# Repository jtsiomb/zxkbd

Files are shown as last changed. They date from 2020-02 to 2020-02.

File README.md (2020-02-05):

ZX Spectrum PS/2 keyboard controller
====================================

About
-----
This project is an PS/2 keyboard controller for the ZX Spectrum. It makes it
possible to connect and use an external PS/2 keyboard with the spectrum. It's
based on the a500kbd code: https://github.com/jtsiomb/a500kbd

The PS/2 keyboard controller is built around an AVR atmega168 microcontroller.
The firmware reads PS/2 keyboard scancodes, maintains a virtual spectrum
keyboard state, and monitors the address bus to keep the data lines going into
the ULA continuously up to date with the selected key row state.

NOTE: not done. check back soon.

License
-------
Copyright (C) 2020 John Tsiombikas <nuclear@member.fsf.org>

You are free to use, reproduce, modify, redistribute any parts of this project,
provided you make any derivative work you release, freely available under the
same terms.

More specifically the hardware design is released under the Creative Commons
Attribution Share-Alike license (see `LICENSE.hw` for details), and the
software/firmware is released under the GNU General Public License v3, or later
(see `LICENSE.fw` for details).

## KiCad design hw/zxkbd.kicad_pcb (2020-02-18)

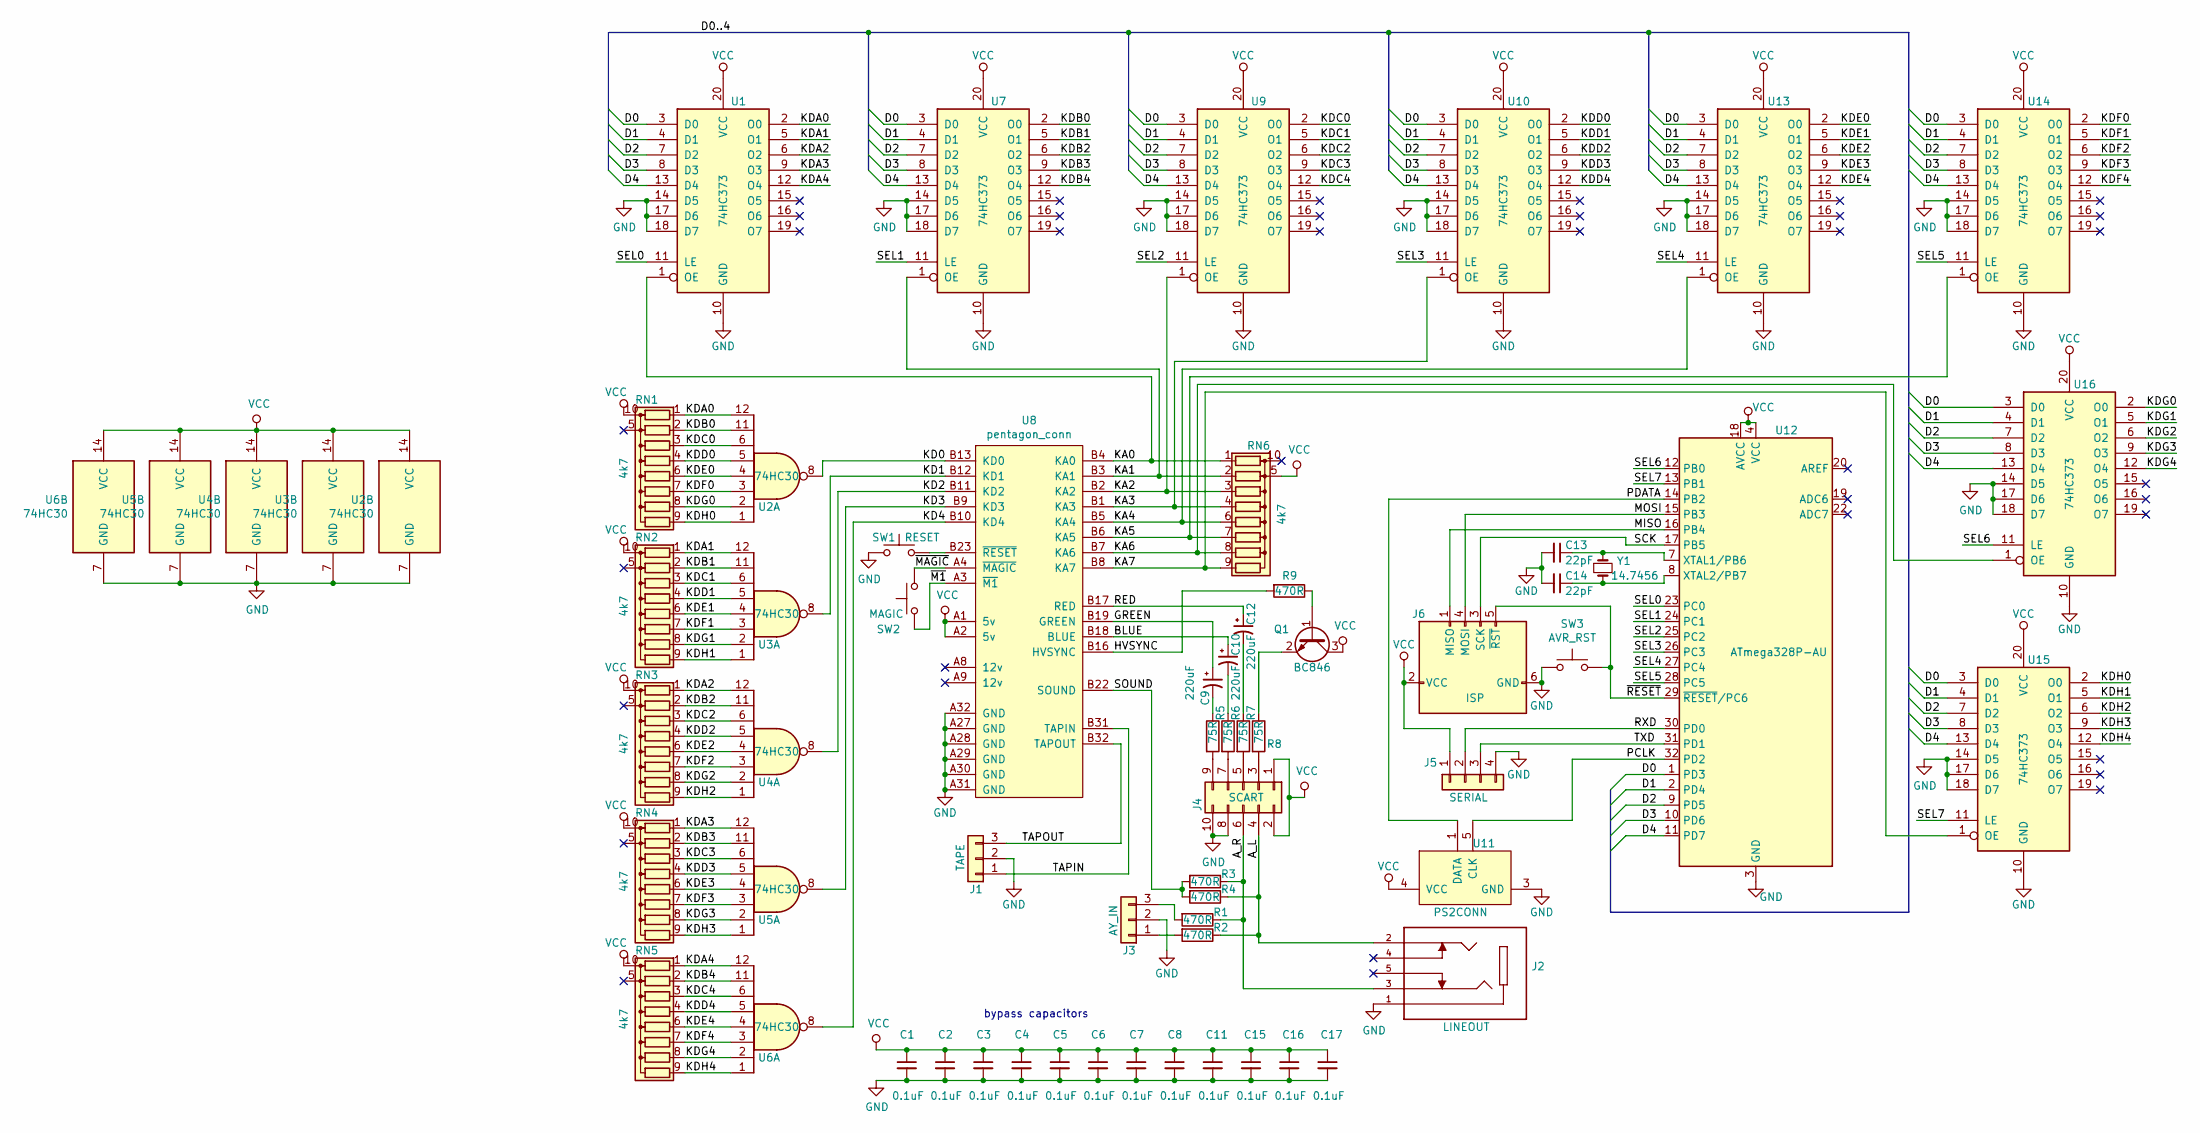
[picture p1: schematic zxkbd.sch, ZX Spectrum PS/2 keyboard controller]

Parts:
C1, C2, C3, C4, C5, C6, C7, C8, C11, C15, C16, C17: 0.1uF; C_0805_2012Metric_Pad1.15x1.40mm_HandSolder
C9, C10, C12: 220uF; CP_Elec_6.3x7.7
C13, C14: 22pF; C_0805_2012Metric_Pad1.15x1.40mm_HandSolder
J1: TAPE; PinHeader_1x03_P2.54mm_Vertical
J2: LINEOUT; cui_sj1-3525ng
J3: AY_IN; PinHeader_1x03_P2.54mm_Vertical
J4: SCART; IDC-Header_2x05_P2.54mm_Vertical
J5: SERIAL; PinHeader_1x04_P2.54mm_Vertical
J6: ISP; IDC-Header_2x03_P2.54mm_Vertical
Q1: BC846; SOT-23
R1, R2, R3, R4, R9: 470R; R_0805_2012Metric_Pad1.15x1.40mm_HandSolder
R5, R6, R7, R8: 75R; R_0805_2012Metric_Pad1.15x1.40mm_HandSolder
RN1, RN2, RN3, RN4, RN5, RN6: 4k7; R_Array_Convex_5x1206
SW1: RESET; SW_Push_1P1T_NO_6x6mm_H9.5mm
SW2: MAGIC; SW_Push_1P1T_NO_6x6mm_H9.5mm
SW3: AVR_RST; SW_Push_1P1T_NO_6x6mm_H9.5mm
U1, U7, U9, U10, U13, U14, U15, U16: 74HC373; SOIC-20W_7.5x12.8mm_P1.27mm
U2, U3, U4, U5, U6: 74HC30; SOIC-14_3.9x8.7mm_P1.27mm
U8: pentagon_conn; pentconn
U11: PS2CONN; ps2conn
U12: ATmega328P-AU; TQFP-32_7x7mm_P0.8mm
Y1: 14.7456; Crystal_SMD_ECS_CSM3X-2Pin_7.6x4.1mm

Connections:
/A_L: J2.2, J4.4, R2.1, R4.1
/A_R: J2.3, J4.6, R1.1, R3.1
/BLUE: C10.1, U8.B18 (BLUE)
/D0: U1.3 (D0), U7.3 (D0), U9.3 (D0), U10.3 (D0), U12.1 (PD3), U13.3 (D0), U14.3 (D0), U15.3 (D0), U16.3 (D0)
/D1: U1.4 (D1), U7.4 (D1), U9.4 (D1), U10.4 (D1), U12.2 (PD4), U13.4 (D1), U14.4 (D1), U15.4 (D1), U16.4 (D1)
/D2: U1.7 (D2), U7.7 (D2), U9.7 (D2), U10.7 (D2), U12.9 (PD5), U13.7 (D2), U14.7 (D2), U15.7 (D2), U16.7 (D2)
/D3: U1.8 (D3), U7.8 (D3), U9.8 (D3), U10.8 (D3), U12.10 (PD6), U13.8 (D3), U14.8 (D3), U15.8 (D3), U16.8 (D3)
/D4: U1.13 (D4), U7.13 (D4), U9.13 (D4), U10.13 (D4), U12.11 (PD7), U13.13 (D4), U14.13 (D4), U15.13 (D4), U16.13 (D4)
/GREEN: C9.1, U8.B19 (GREEN)
/HVSYNC: R9.2, U8.B16 (HVSYNC)
/KA0: RN6.1 (R1), U1.1 (OE), U8.B4 (KA0)
/KA1: RN6.2 (R2), U7.1 (OE), U8.B3 (KA1)
/KA2: RN6.3 (R3), U8.B2 (KA2), U9.1 (OE)
/KA3: RN6.4 (R4), U8.B1 (KA3), U10.1 (OE)
/KA4: RN6.6 (R6), U8.B5 (KA4), U13.1 (OE)
/KA5: RN6.7 (R7), U8.B6 (KA5), U14.1 (OE)
/KA6: RN6.8 (R8), U8.B7 (KA6), U16.1 (OE)
/KA7: RN6.9 (R9), U8.B8 (KA7), U15.1 (OE)
/KD0: U2.8, U8.B13 (KD0)
/KD1: U3.8, U8.B12 (KD1)
/KD2: U4.8, U8.B11 (KD2)
/KD3: U5.8, U8.B9 (KD3)
/KD4: U6.8, U8.B10 (KD4)
/KDA0: RN1.1 (R1), U1.2 (O0), U2.12
/KDA1: RN2.1 (R1), U1.5 (O1), U3.12
/KDA2: RN3.1 (R1), U1.6 (O2), U4.12
/KDA3: RN4.1 (R1), U1.9 (O3), U5.12
/KDA4: RN5.1 (R1), U1.12 (O4), U6.12
/KDB0: RN1.2 (R2), U2.11, U7.2 (O0)
/KDB1: RN2.2 (R2), U3.11, U7.5 (O1)
/KDB2: RN3.2 (R2), U4.11, U7.6 (O2)
/KDB3: RN4.2 (R2), U5.11, U7.9 (O3)
/KDB4: RN5.2 (R2), U6.11, U7.12 (O4)
/KDC0: RN1.3 (R3), U2.6, U9.2 (O0)
/KDC1: RN2.3 (R3), U3.6, U9.5 (O1)
/KDC2: RN3.3 (R3), U4.6, U9.6 (O2)
/KDC3: RN4.3 (R3), U5.6, U9.9 (O3)
/KDC4: RN5.3 (R3), U6.6, U9.12 (O4)
/KDD0: RN1.4 (R4), U2.5, U10.2 (O0)
/KDD1: RN2.4 (R4), U3.5, U10.5 (O1)
/KDD2: RN3.4 (R4), U4.5, U10.6 (O2)
/KDD3: RN4.4 (R4), U5.5, U10.9 (O3)
/KDD4: RN5.4 (R4), U6.5, U10.12 (O4)
/KDE0: RN1.6 (R6), U2.4, U13.2 (O0)
/KDE1: RN2.6 (R6), U3.4, U13.5 (O1)
/KDE2: RN3.6 (R6), U4.4, U13.6 (O2)
/KDE3: RN4.6 (R6), U5.4, U13.9 (O3)
/KDE4: RN5.6 (R6), U6.4, U13.12 (O4)
/KDF0: RN1.7 (R7), U2.3, U14.2 (O0)
/KDF1: RN2.7 (R7), U3.3, U14.5 (O1)
/KDF2: RN3.7 (R7), U4.3, U14.6 (O2)
/KDF3: RN4.7 (R7), U5.3, U14.9 (O3)
/KDF4: RN5.7 (R7), U6.3, U14.12 (O4)
/KDG0: RN1.8 (R8), U2.2, U16.2 (O0)
/KDG1: RN2.8 (R8), U3.2, U16.5 (O1)
/KDG2: RN3.8 (R8), U4.2, U16.6 (O2)
/KDG3: RN4.8 (R8), U5.2, U16.9 (O3)
/KDG4: RN5.8 (R8), U6.2, U16.12 (O4)
/KDH0: RN1.9 (R9), U2.1, U15.2 (O0)
/KDH1: RN2.9 (R9), U3.1, U15.5 (O1)
/KDH2: RN3.9 (R9), U4.1, U15.6 (O2)
/KDH3: RN4.9 (R9), U5.1, U15.9 (O3)
/KDH4: RN5.9 (R9), U6.1, U15.12 (O4)
/MISO: J6.1 (MISO), U12.16 (PB4)
/MOSI: J6.4 (MOSI), U12.15 (PB3)
/PCLK: U11.5 (CLK), U12.32 (PD2)
/PDATA: U11.1 (DATA), U12.14 (PB2)
/RED: C12.1, U8.B17 (RED)
/RXD: J5.2, U12.30 (PD0)
/SCK: J6.3 (SCK), U12.17 (PB5)
/SEL0: U1.11 (LE), U12.23 (PC0)
/SEL1: U7.11 (LE), U12.24 (PC1)
/SEL2: U9.11 (LE), U12.25 (PC2)
/SEL3: U10.11 (LE), U12.26 (PC3)
/SEL4: U12.27 (PC4), U13.11 (LE)
/SEL5: U12.28 (PC5), U14.11 (LE)
/SEL6: U12.12 (PB0), U16.11 (LE)
/SEL7: U12.13 (PB1), U15.11 (LE)
/SOUND: R3.2, R4.2, U8.B22 (SOUND)
/TAPIN: J1.1, U8.B31 (TAPIN)
/TAPOUT: J1.3, U8.B32 (TAPOUT)
/TXD: J5.3, U12.31 (PD1)
/~M1: SW2.1, U8.A3 (~M1)
/~MAGIC: SW2.2, U8.A4 (~MAGIC)
/~RESET: J6.5 (~RST), SW3.2, U12.29 (~RESET~/PC6)
GND: C1.2, C2.2, C3.2, C4.2, C5.2, C6.2, C7.2, C8.2, C11.2, C13.2, C14.2, C15.2, C16.2, C17.2, J1.2, J2.1, J3.2, J4.8, J4.10, J5.4, J6.6 (GND), SW1.1, SW3.1, U1.10 (GND), U1.14 (D5), U1.17 (D6), U1.18 (D7), U2.7 (GND), U3.7 (GND), U4.7 (GND), U5.7 (GND), U6.7 (GND), U7.10 (GND), U7.14 (D5), U7.17 (D6), U7.18 (D7), U8.A27 (GND), U8.A28 (GND), U8.A29 (GND), U8.A30 (GND), U8.A31 (GND), U8.A32 (GND), U9.10 (GND), U9.14 (D5), U9.17 (D6), U9.18 (D7), U10.10 (GND), U10.14 (D5), U10.17 (D6), U10.18 (D7), U11.3 (GND), U12.3 (GND), U12.5 (GND), U12.21 (GND), U13.10 (GND), U13.14 (D5), U13.17 (D6), U13.18 (D7), U14.10 (GND), U14.14 (D5), U14.17 (D6), U14.18 (D7), U15.10 (GND), U15.14 (D5), U15.17 (D6), U15.18 (D7), U16.10 (GND), U16.14 (D5), U16.17 (D6), U16.18 (D7)
unnamed: C9.2, R5.1
unnamed: C10.2, R6.1
unnamed: C12.2, R7.1
unnamed: C13.1, U12.7 (XTAL1/PB6), Y1.1
unnamed: C14.1, U12.8 (XTAL2/PB7), Y1.2
unnamed: J3.1, R2.2
unnamed: J3.3, R1.2
unnamed: J4.3, R8.2
unnamed: J4.5, R7.2
unnamed: J4.7, R6.2
unnamed: J4.9, R5.2
unnamed: Q1.1 (B), R9.1
unnamed: Q1.2 (E), R8.1
unnamed: SW1.2, U8.B23 (~RESET)
VCC: C1.1, C2.1, C3.1, C4.1, C5.1, C6.1, C7.1, C8.1, C11.1, C15.1, C16.1, C17.1, J4.1, J4.2, J5.1, J6.2 (VCC), Q1.3 (C), RN1.10 (common), RN2.10 (common), RN3.10 (common), RN4.10 (common), RN5.10 (common), RN6.5 (common), U1.20 (VCC), U2.14 (VCC), U3.14 (VCC), U4.14 (VCC), U5.14 (VCC), U6.14 (VCC), U7.20 (VCC), U8.A1 (5v), U8.A2 (5v), U9.20 (VCC), U10.20 (VCC), U11.4 (VCC), U12.4 (VCC), U12.6 (VCC), U12.18 (AVCC), U13.20 (VCC), U14.20 (VCC), U15.20 (VCC), U16.20 (VCC)

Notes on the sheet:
bypass capacitors

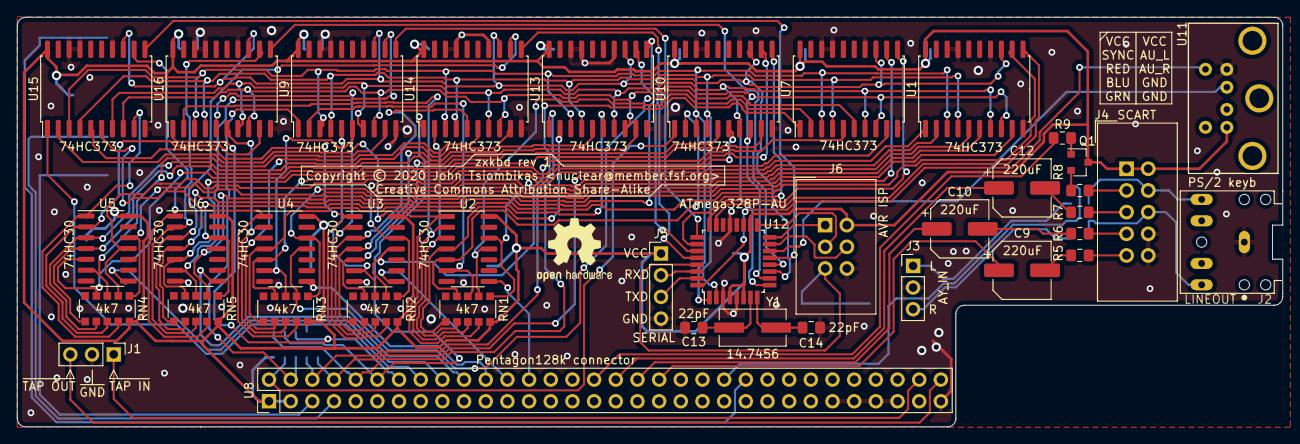
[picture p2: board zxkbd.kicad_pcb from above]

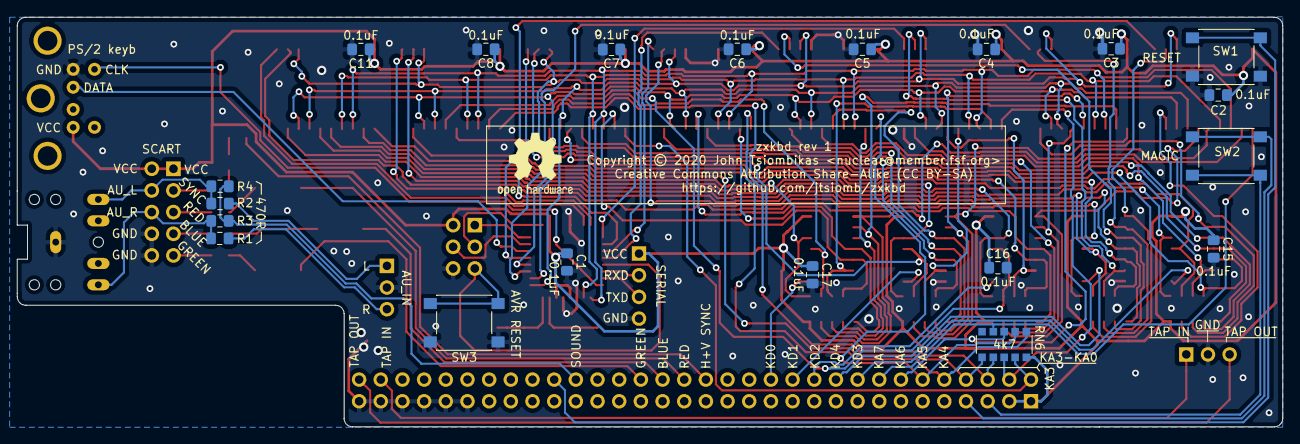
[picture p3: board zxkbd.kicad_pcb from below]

Board: 2 copper layers, 148.3 x 48.0 mm, 59 parts (20 on the bottom side), 101 nets.

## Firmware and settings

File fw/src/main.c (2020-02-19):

#include <stdio.h>
#include <ctype.h>
#include <avr/io.h>
#include <avr/interrupt.h>
#include <util/delay.h>
#include "serial.h"
#include "scantbl.h"
#include "ps2kbd.h"
#include "defs.h"
#include "timer.h"
#include "zxkbd.h"
#include "ansi.h"

enum {
	KF_BRK = 1,
	KF_EXT = 2,
	KF_EXT1 = 4,
};
#define KF_TRANSIENT	0x0f
#define KF_STICKY		0xf0

#define RESET_WAIT 1000



int main(void)
{
	unsigned int keyflags = 0;
	unsigned char c;
	int keycode;

	/* disable all pullups globally */
	MCUCR |= 1 << PUD;

	/* start with all latch signals off (high) */
	DDRC = 0xff;
	PORTC = 0xff;
	DDRB = 3;
	PORTB = 3;

	/* data bits as outputs */
	DDRD = 0xf8;
	PORTD = 0xf8;

	EIMSK = 0;	/* mask external interrupts */
	EICRA = 1 << ISC01;	/* falling edge of PCLK triggers interrupt */

	init_timer();

	/* initialize the UART and enable interrupts */
	init_serial(9600);
	sei();

	ansi_reset();
	ansi_clearscr();
	ansi_cursor(0);
	printf("PS/2 keyboard controller - John Tsiombikas <nuclear@member.fsf.org>\r\n");
	fflush(stdout);

	EIMSK = 1 << INT0;	/* enable ps/2 clock interrupt */

	_delay_ms(500);
	ps2setled(PS2LED_NUMLK);
	_delay_ms(200);
	ps2setled(PS2LED_CAPSLK);
	_delay_ms(200);
	ps2setled(PS2LED_SCRLK);
	_delay_ms(200);
	ps2setled(PS2LED_CAPSLK);
	_delay_ms(200);
	ps2setled(PS2LED_NUMLK);
	_delay_ms(200);
	ps2setled(0);	/* start with all LEDs off */

	for(;;) {
		if(ps2pending()) {
			c = ps2read();
			switch(c) {
			case 0xe0:	/* extended */
				keyflags |= KF_EXT;
				break;

			case 0xe1:	/* extended */
				keyflags |= KF_EXT1;
				break;

			case 0xf0:	/* break code */
				keyflags |= KF_BRK;
				break;

			default:
				keycode = -1;
				if(keyflags & KF_EXT) {
					if(c < KEYMAP_EXT_SIZE) {
						keycode = keymap_ext[(int)c];
					}
				} else if(keyflags & KF_EXT1) {
				} else {
					if(c < KEYMAP_NORMAL_SIZE) {
						keycode = keymap_normal[(int)c];
					}
				}

				if(keycode != -1) {
					int press = ~keyflags & KF_BRK;
					zxkbd_key(keycode, press);
				} else {
					printf("PS/2 unknown command or keycode: %x\r\n", (unsigned int)c);
				}
				keyflags &= ~KF_TRANSIENT;
			}
		}
	}
	return 0;
}

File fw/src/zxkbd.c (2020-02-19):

#include <stdio.h>
#include "ansi.h"
#include "defs.h"

enum {
	RCAPS = 0, RZ = 0, RX = 0, RC = 0, RV = 0,
	RA = 1, RS = 1, RD = 1, RF = 1, RG = 1,
	RQ = 2, RW = 2, RE = 2, RR = 2, RT = 2,
	R1 = 3, R2 = 3, R3 = 3, R4 = 3, R5 = 3,
	R0 = 4, R9 = 4, R8 = 4, R7 = 4, R6 = 4,
	RP = 5, RO = 5, RI = 5, RU = 5, RY = 5,
	RENTER = 6, RL = 6, RK = 6, RJ = 6, RH = 6,
	RSPACE = 7, RSYMB = 7, RM = 7, RN = 7, RB = 7
};

enum {
	CCAPS = 0, CZ = 1, CX = 2, CC = 3, CV = 4,
	CA = 0, CS = 1, CD = 2, CF = 3, CG = 4,
	CQ = 0, CW = 1, CE = 2, CR = 3, CT = 4,
	C1 = 0, C2 = 1, C3 = 2, C4 = 3, C5 = 4,
	C0 = 0, C9 = 1, C8 = 2, C7 = 3, C6 = 4,
	CP = 0, CO = 1, CI = 2, CU = 3, CY = 4,
	CENTER = 0, CL = 1, CK = 2, CJ = 3, CH = 4,
	CSPACE = 0, CSYMB = 1, CM = 2, CN = 3, CB = 4
};

#define KEY(x)		(0xf0 | (x))
#define PAIR(x, y)	((x) << 4 | (y))


/* row of modifier (high order nibble) and key (low order nibble) for each keycode */
static const unsigned char keyrow[] = {
	0xff, 0xff, 0xff, 0xff, 0xff, 0xff, 0xff, 0xff,						/* 00 - 07 */
	0xff, 0xff, KEY(RENTER), 0xff, 0xff, KEY(RENTER), 0xff, 0xff,		/* 08 - 0f */
	0xff, 0xff, 0xff, 0xff, 0xff, 0xff, 0xff, 0xff,						/* 10 - 17 */
	0xff, 0xff, 0xff, PAIR(RCAPS, RSPACE), 0xff, 0xff, 0xff, 0xff,		/* 18 - 1f */
	KEY(RSPACE), PAIR(RSYMB, R1), PAIR(RSYMB, RP), PAIR(RSYMB, R3),		/* 20 - 23 */
	PAIR(RSYMB, R4), PAIR(RSYMB, R5), PAIR(RSYMB, R6), PAIR(RSYMB, R7),	/* 23 - 27 */
	PAIR(RSYMB, R8), PAIR(RSYMB, R9), PAIR(RSYMB, RB), PAIR(RSYMB, RK), /* 28 - 2b */
	PAIR(RSYMB, RN), PAIR(RSYMB, RJ), PAIR(RSYMB, RM), PAIR(RSYMB, RV), /* 2c - 2f */
	KEY(R0), KEY(R1), KEY(R2), KEY(R3), KEY(R4), KEY(R5), KEY(R6), KEY(R7),	/* 30 - 37 */
	KEY(R8), KEY(R9), PAIR(RSYMB, RZ), PAIR(RSYMB, RO),					/* 38 - 3b */
	PAIR(RSYMB, RR), PAIR(RSYMB, RL), PAIR(RSYMB, RT), PAIR(RSYMB, RC),	/* 3c - 3f */
	PAIR(RSYMB, R2), KEY(RA), KEY(RB), KEY(RC), KEY(RD), KEY(RE), KEY(RF), KEY(RG),	/* 40 - 47 */
	KEY(RH), KEY(RI), KEY(RJ), KEY(RK), KEY(RL), KEY(RM), KEY(RN), KEY(RO),	/* 48 - 4f */
	KEY(RP), KEY(RQ), KEY(RR), KEY(RS), KEY(RT), KEY(RU), KEY(RV), KEY(RW),	/* 50 - 57 */
	KEY(RX), KEY(RY), KEY(RZ), 0xff, 0xff, 0xff, PAIR(RSYMB, RH), PAIR(RSYMB, R0),	/* 58 - 5f */
	0xff, 0xff, 0xff, 0xff, 0xff, 0xff, 0xff, 0xff,						/* 60 - 67 */
	0xff, 0xff, 0xff, 0xff, 0xff, 0xff, 0xff, 0xff,						/* 68 - 6f */
	0xff, 0xff, 0xff, 0xff, 0xff, 0xff, 0xff, 0xff,						/* 70 - 77 */
	0xff, 0xff, 0xff, 0xff, 0xff, 0xff, 0xff, PAIR(RCAPS, R0),			/* 78 - 7f */
	0xff, 0xff, 0xff, 0xff, 0xff, 0xff, 0xff, 0xff,						/* 80 - 87 */
	0xff, 0xff, 0xff, 0xff, 0xff, PAIR(RCAPS, RSPACE), 0xff, PAIR(RCAPS, R2),	/* 88 - 8f */
	0xff, KEY(RCAPS), KEY(RCAPS), 0xff, 0xff, KEY(RSYMB), KEY(RSYMB),	/* 90 - 97 */
	0xff, 0xff, 0xff, 0xff, 0xff, 0xff, 0xff, 0xff,						/* 98 - 9f */
	PAIR(RCAPS, R5), PAIR(RCAPS, R8), PAIR(RCAPS, R7), PAIR(RCAPS, R6), 0xff, 0xff, 0xff, 0xff,	/* a0 - a7 */
	0xff, 0xff, 0xff, 0xff, 0xff, 0xff, PAIR(RSYMB, RV), PAIR(RSYMB, RB),	/* a8 - af */
	PAIR(RSYMB, RJ), PAIR(RSYMB, RK), PAIR(RSYMB, RM), KEY(RENTER)	/* b0 - b3 */
};

/* column of modifier (high order nibble) and key (low order nibble) for each keycode */
static const unsigned char keycol[] = {
	0xff, 0xff, 0xff, 0xff, 0xff, 0xff, 0xff, 0xff,						/* 00 - 07 */
	0xff, 0xff, KEY(CENTER), 0xff, 0xff, KEY(CENTER), 0xff, 0xff,		/* 08 - 0f */
	0xff, 0xff, 0xff, 0xff, 0xff, 0xff, 0xff, 0xff,						/* 10 - 17 */
	0xff, 0xff, 0xff, PAIR(CCAPS, CSPACE), 0xff, 0xff, 0xff, 0xff,		/* 18 - 1f */
	KEY(CSPACE), PAIR(CSYMB, C1), PAIR(CSYMB, CP), PAIR(CSYMB, C3),		/* 20 - 23 */
	PAIR(CSYMB, C4), PAIR(CSYMB, C5), PAIR(CSYMB, C6), PAIR(CSYMB, C7),	/* 23 - 27 */
	PAIR(CSYMB, C8), PAIR(CSYMB, C9), PAIR(CSYMB, CB), PAIR(CSYMB, CK), /* 28 - 2b */
	PAIR(CSYMB, CN), PAIR(CSYMB, CJ), PAIR(CSYMB, CM), PAIR(CSYMB, CV), /* 2c - 2f */
	KEY(C0), KEY(C1), KEY(C2), KEY(C3), KEY(C4), KEY(C5), KEY(C6), KEY(C7),	/* 30 - 37 */
	KEY(C8), KEY(C9), PAIR(CSYMB, CZ), PAIR(CSYMB, CO),					/* 38 - 3b */
	PAIR(CSYMB, CR), PAIR(CSYMB, CL), PAIR(CSYMB, CT), PAIR(CSYMB, CC),	/* 3c - 3f */
	PAIR(CSYMB, C2), KEY(CA), KEY(CB), KEY(CC), KEY(CD), KEY(CE), KEY(CF), KEY(CG),	/* 40 - 47 */
	KEY(CH), KEY(CI), KEY(CJ), KEY(CK), KEY(CL), KEY(CM), KEY(CN), KEY(CO),	/* 48 - 4f */
	KEY(CP), KEY(CQ), KEY(CR), KEY(CS), KEY(CT), KEY(CU), KEY(CV), KEY(CW),	/* 50 - 57 */
	KEY(CX), KEY(CY), KEY(CZ), 0xff, 0xff, 0xff, PAIR(CSYMB, CH), PAIR(CSYMB, C0),	/* 58 - 5f */
	0xff, 0xff, 0xff, 0xff, 0xff, 0xff, 0xff, 0xff,						/* 60 - 67 */
	0xff, 0xff, 0xff, 0xff, 0xff, 0xff, 0xff, 0xff,						/* 68 - 6f */
	0xff, 0xff, 0xff, 0xff, 0xff, 0xff, 0xff, 0xff,						/* 70 - 77 */
	0xff, 0xff, 0xff, 0xff, 0xff, 0xff, 0xff, PAIR(CCAPS, C0),			/* 78 - 7f */
	0xff, 0xff, 0xff, 0xff, 0xff, 0xff, 0xff, 0xff,						/* 80 - 87 */
	0xff, 0xff, 0xff, 0xff, 0xff, PAIR(CCAPS, CSPACE), 0xff, PAIR(CCAPS, C2),	/* 88 - 8f */
	0xff, KEY(CCAPS), KEY(CCAPS), 0xff, 0xff, KEY(CSYMB), KEY(CSYMB),	/* 90 - 97 */
	0xff, 0xff, 0xff, 0xff, 0xff, 0xff, 0xff, 0xff,						/* 98 - 9f */
	PAIR(CCAPS, C5), PAIR(CCAPS, C8), PAIR(CCAPS, C7), PAIR(CCAPS, C6), 0xff, 0xff, 0xff, 0xff,	/* a0 - a7 */
	0xff, 0xff, 0xff, 0xff, 0xff, 0xff, PAIR(CSYMB, CV), PAIR(CSYMB, CB),	/* a8 - af */
	PAIR(CSYMB, CJ), PAIR(CSYMB, CK), PAIR(CSYMB, CM), KEY(CENTER)	/* b0 - b3 */
};

static unsigned char keystate[8];

static void update_row(int row);

void zxkbd_key(int keycode, int press)
{
	/*int i, j;*/
	unsigned char row, col, krow, kcol, mrow, mcol, mask;
	unsigned char prev, kdirty = 0, mdirty = 0;

	/*
	ansi_setcursor(1, 0);
	printf("%s %x        ", press ? "  press" : "release", (unsigned int)keycode);
	*/

	row = keyrow[keycode];
	if(row == 0xff) return;
	col = keycol[keycode];

	krow = row & 0xf;
	kcol = col & 0xf;
	mrow = row >> 4;

	prev = keystate[krow];
	mask = 1 << kcol;
	if(press) {
		keystate[krow] |= mask;
	} else {
		keystate[krow] &= ~mask;
	}
	kdirty = keystate[krow] ^ prev;

	if(mrow != 0xf) {
		prev = keystate[mrow];
		mcol = col >> 4;
		mask = 1 << mcol;

		if(press) {
			keystate[mrow] |= mask;
		} else {
			keystate[mrow] &= ~mask;
		}
		mdirty = keystate[mrow] ^ prev;
	}

	if(kdirty) {
		update_row(krow);
		if(mdirty && mrow != krow) {
			update_row(mrow);
		}
	}

	/*
	ansi_setcursor(3, 0);
	printf("ZX Keystate:\r\n");
	for(i=0; i<8; i++) {
		printf("row[%d]: ", i);
		mask = 0x10;
		for(j=0; j<5; j++) {
			putchar(keystate[i] & mask ? '1' : '0');
			mask >>= 1;
		}
		fputs("\r\n", stdout);
	}
	fflush(stdout);
	*/
}

static void update_row(int row)
{
	unsigned char selbit;

	/* setup the data pins */
	PORTD = keystate[row] << 3;
	/* latch on the correct register */
	if(row < 6) {
		selbit = 1 << row;
		PORTC = ~selbit;
		asm volatile("nop");	/* for good measure, probably not needed */
		PORTC = selbit;
	} else {
		selbit = 1 << (row - 6);
		PORTB = ~selbit;
		asm volatile("nop");	/* same */
		PORTB = selbit;
	}
}

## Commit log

2020-02-12 started on the hardware design
    [zxkbd.kicad_pcb, zxkbd.sch]
2020-02-13 added resistor network symbol
2020-02-15 designing the pcb
    [zxkbd.kicad_pcb, zxkbd.sch]
2020-02-17 PCB first pass
    [zxkbd.kicad_pcb, zxkbd.sch]
2020-02-17 via stitching
    [zxkbd.kicad_pcb]
2020-02-17 fixed PCB mistake, AVR reset switch overlapped with ISP header pins on the back side of the board.
    [zxkbd.kicad_pcb]
2020-02-18 finishing the pcb
    [zxkbd.kicad_pcb, zxkbd.sch]
2020-02-18 labels on the pcb
    [zxkbd.kicad_pcb]
2020-02-18 PCB completed
    [zxkbd-B_Cu.gbr, zxkbd-B_Mask.gbr, zxkbd-B_Paste.gbr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]
2020-02-19 added bom
2020-03-19 corrected BOM

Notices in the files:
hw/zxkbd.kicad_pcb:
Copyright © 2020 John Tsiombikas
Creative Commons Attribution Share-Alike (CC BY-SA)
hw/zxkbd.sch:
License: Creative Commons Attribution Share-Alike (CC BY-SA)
